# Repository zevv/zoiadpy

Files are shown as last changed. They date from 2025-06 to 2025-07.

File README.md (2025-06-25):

# Experimental external display for the Empress Zoia

The repo holds the source code and schematics/pcb design for an external
display for the Zoia. The Zoia comes with a screen so small you can cover it
with the tip of your pinky. This is barely usable when prgramming the Zoia on
your couch, but totally useless on stage when changing programs or parameters.

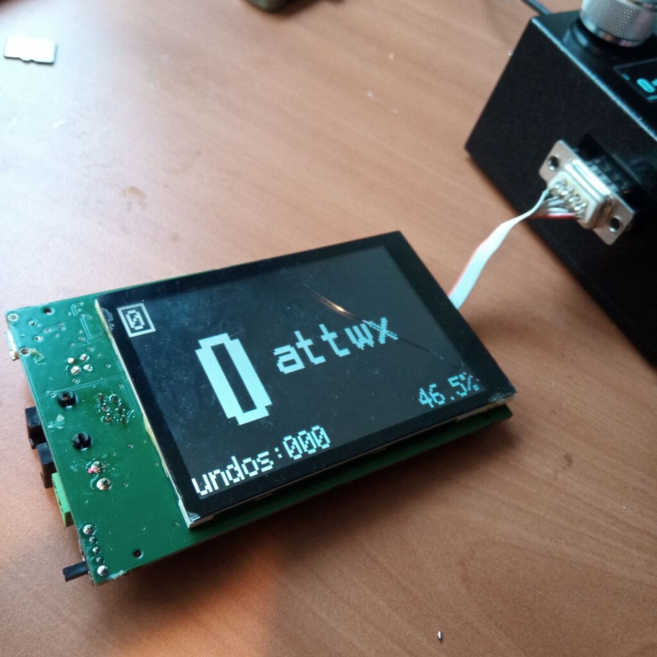
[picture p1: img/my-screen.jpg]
my-screen


This external display hooks onto the SPI bus between the Zoia en the tiny OLED
display and sniffs the screen contents when the display is updated. The screen
is upscaled to 480x320 resolution and sent to a second larger display.

The Zoia luckily exposes the OLED SPI on a friendly 2.54mm header row, so
anyone with basic soldering skills should be able to connect some wires to
these and feed them out of the box. I used a retro style DB9 type connector
for this myself, as this happened to be available in my parts drawer. You
need 5 wires in total, so any connector with enough pins should do:

- GND
- VCC
- MOSI
- CLK
- CS

# Disclaimer

I love this little project for me personally, but I do not recommend others to
go hack their Zoia: you will surely void the warranty of your box, and it is
very possible it will break in the process of adding the screen. Do not
complain to me when this happens.

# Software

Not too complicated: ESP32 has a bunch of SPI busses and supports both master
and slave mode. The OLED SPI is running in slave mode and handles all SPI
transfers of exactly 1024 bytes, as these contain the full updated screen data.
All other SPI transfers are simply ignored, as these contain the usual setup
parameters for the display.

The second SPI runs in master mode and drives an ILI4822 type TFT display which
I happened to have lying around. Although this is a full color display, it's
driven in 3 bits per pixel mode only to allow the big screen to keep up with
the OLED frame rate.

# Hardware

Kicad schematics and PCB design are available, but I have not yet produced this
as I'm happy to run on my current prototype hardware. I'm sure these are mostly
ok but someone will have to actually build and test these to make sure. I might
do this one day.

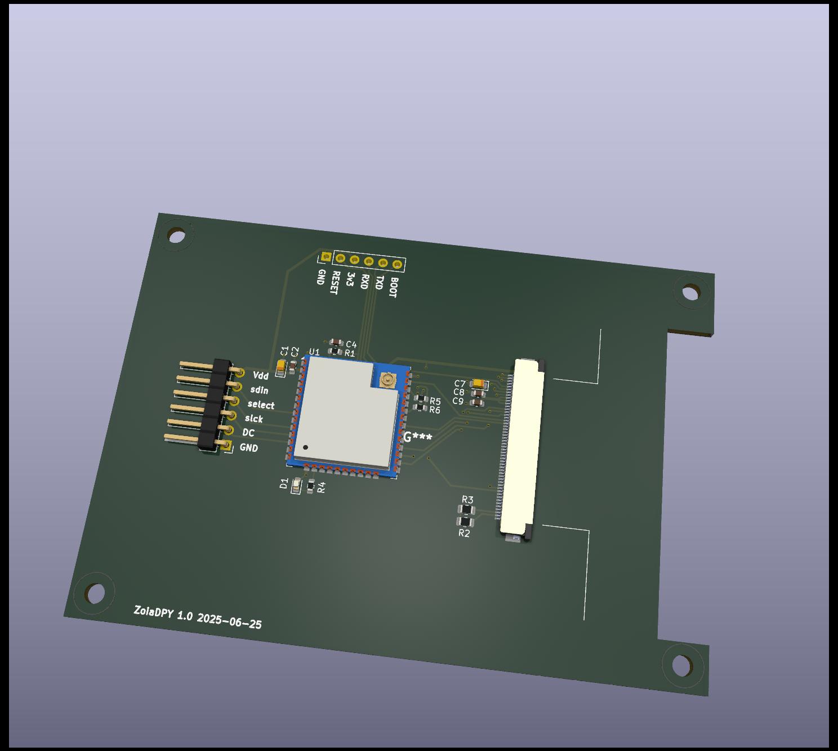
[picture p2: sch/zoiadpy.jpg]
pcb


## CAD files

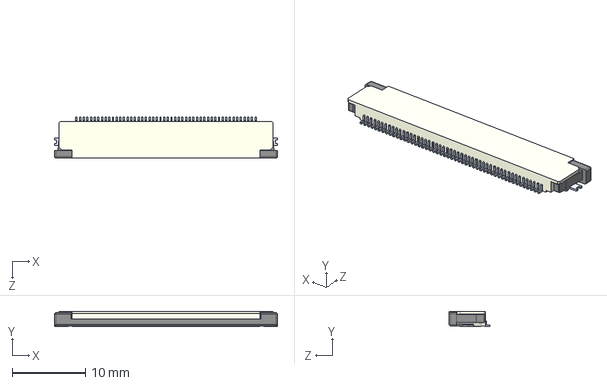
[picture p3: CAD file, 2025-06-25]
sch/62684-50210E9ALF.step
30.5 x 2.00 x 5.60 mm
62684 additional-21 body_50
pin^62684 additional-21 ASS x 50

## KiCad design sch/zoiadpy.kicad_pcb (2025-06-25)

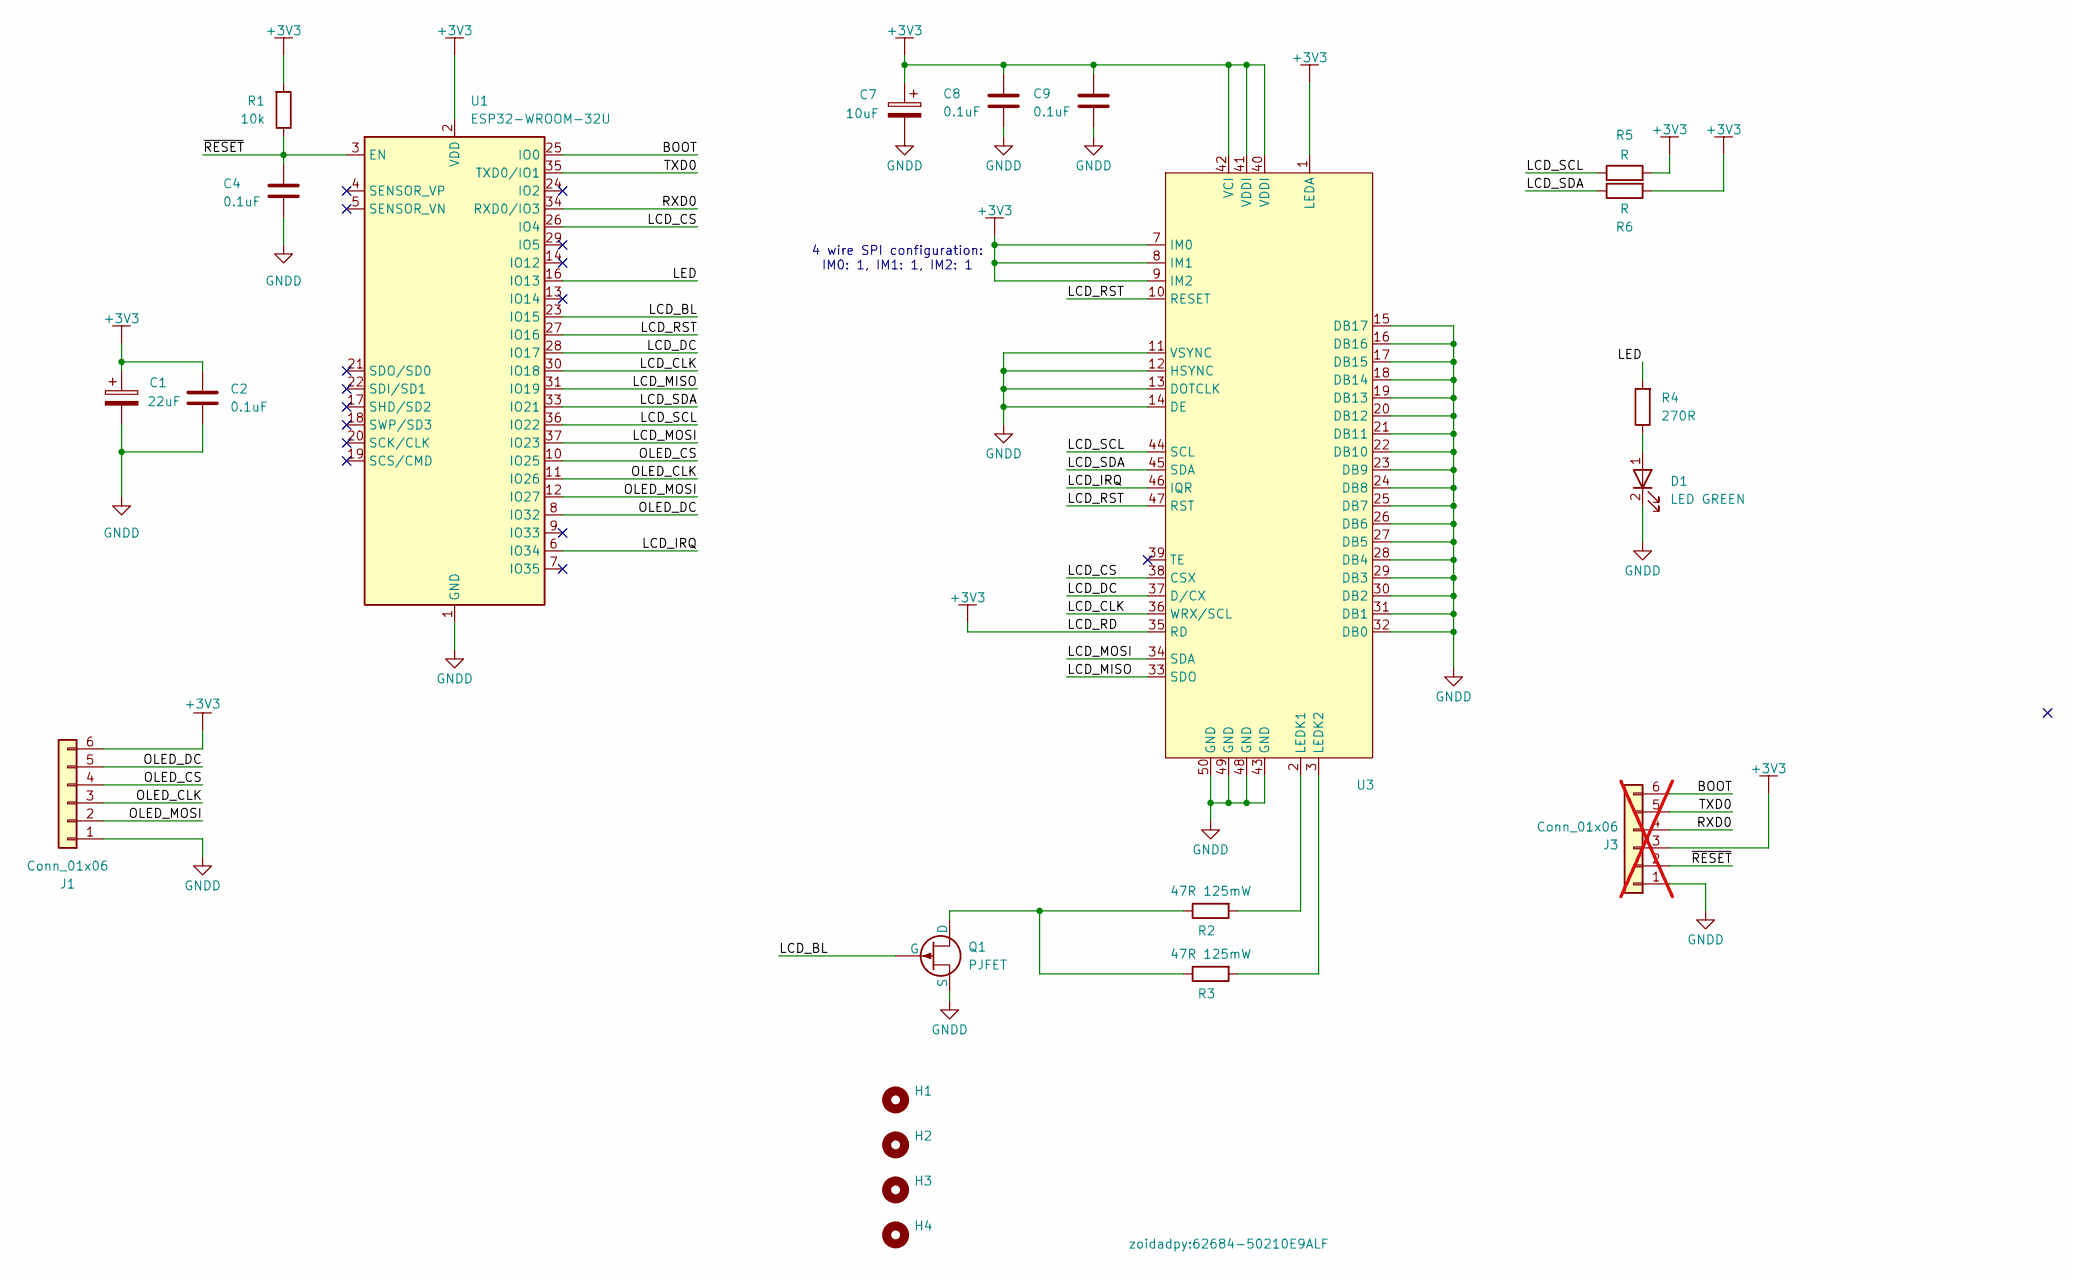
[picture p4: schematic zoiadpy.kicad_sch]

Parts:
C1: 22uF; CP_EIA-2012-12_Kemet-R; JLC C5674
C2, C4, C8, C9: 0.1uF; C_0603_1608Metric
C7: 10uF; CP_EIA-2012-12_Kemet-R; JLC C5674
D1: LED GREEN; LED_0603_1608Metric
H1, H2, H3, H4: MountingHole; MountingHole_3.2mm_M3
J1: Conn_01x06; PinHeader_1x06_P2.54mm_Horizontal
J3: Conn_01x06; PinHeader_1x06_P2.54mm_Vertical; not fitted
Q1: PJFET
R1: 10k; R_0603_1608Metric
R2, R3: 47R 125mW; R_0805_2012Metric
R4: 270R; R_0603_1608Metric; Farnell 2141320
R5, R6: R; R_0603_1608Metric
U1: ESP32-WROOM-32U
U3: 62684-50210E9ALF

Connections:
+3V3: C1.1, C2.1, C7.1, C8.1, C9.1, J1.6, J3.3, R1.2, R5.2, R6.2, U1.2 (VDD), U3.1 (LEDA), U3.7 (IM0), U3.8 (IM1), U3.9 (IM2), U3.35 (RD), U3.40 (VDDI), U3.41 (VDDI), U3.42 (VCI)
/BOOT: J3.6, U1.25 (IO0)
/LCD_BL: Q1.2 (G), U1.23 (IO15)
/LCD_CLK: U1.30 (IO18), U3.36 (WRX/SCL)
/LCD_CS: U1.26 (IO4), U3.38 (CSX)
/LCD_DC: U1.28 (IO17), U3.37 (D/CX)
/LCD_IRQ: U1.6 (IO34), U3.46 (IQR)
/LCD_MISO: U1.31 (IO19), U3.33 (SDO)
/LCD_MOSI: U1.37 (IO23), U3.34 (SDA)
/LCD_RST: U1.27 (IO16), U3.10 (RESET), U3.47 (RST)
/LCD_SCL: R5.1, U1.36 (IO22), U3.44 (SCL)
/LCD_SDA: R6.1, U1.33 (IO21), U3.45 (SDA)
/LED: R4.2, U1.16 (IO13)
/OLED_CLK: J1.3, U1.11 (IO26)
/OLED_CS: J1.4, U1.10 (IO25)
/OLED_DC: J1.5, U1.8 (IO32)
/OLED_MOSI: J1.2, U1.12 (IO27)
/RXD0: J3.4, U1.34 (RXD0/IO3)
/TXD0: J3.5, U1.35 (TXD0/IO1)
/~RESET: C4.1, J3.2, R1.1, U1.3 (EN)
GNDD: C1.2, C2.2, C4.2, C7.2, C8.2, C9.2, D1.2 (K), J1.1, J3.1, Q1.3 (S), U1.1 (GND), U1.15 (GND), U1.38 (GND), U1.39 (GND), U3.11 (VSYNC), U3.12 (HSYNC), U3.13 (DOTCLK), U3.14 (DE), U3.15 (DB17), U3.16 (DB16), U3.17 (DB15), U3.18 (DB14), U3.19 (DB13), U3.20 (DB12), U3.21 (DB11), U3.22 (DB10), U3.23 (DB9), U3.24 (DB8), U3.25 (DB7), U3.26 (DB6), U3.27 (DB5), U3.28 (DB4), U3.29 (DB3), U3.30 (DB2), U3.31 (DB1), U3.32 (DB0), U3.43 (GND), U3.48 (GND), U3.49 (GND), U3.50 (GND)
unnamed: D1.1 (A), R4.1
unnamed: Q1.1 (D), R2.1, R3.1
unnamed: R2.2, U3.2 (LEDK1)
unnamed: R3.2, U3.3 (LEDK2)

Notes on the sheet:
4 wire SPI configuration: IM0: 1, IM1: 1, IM2: 1

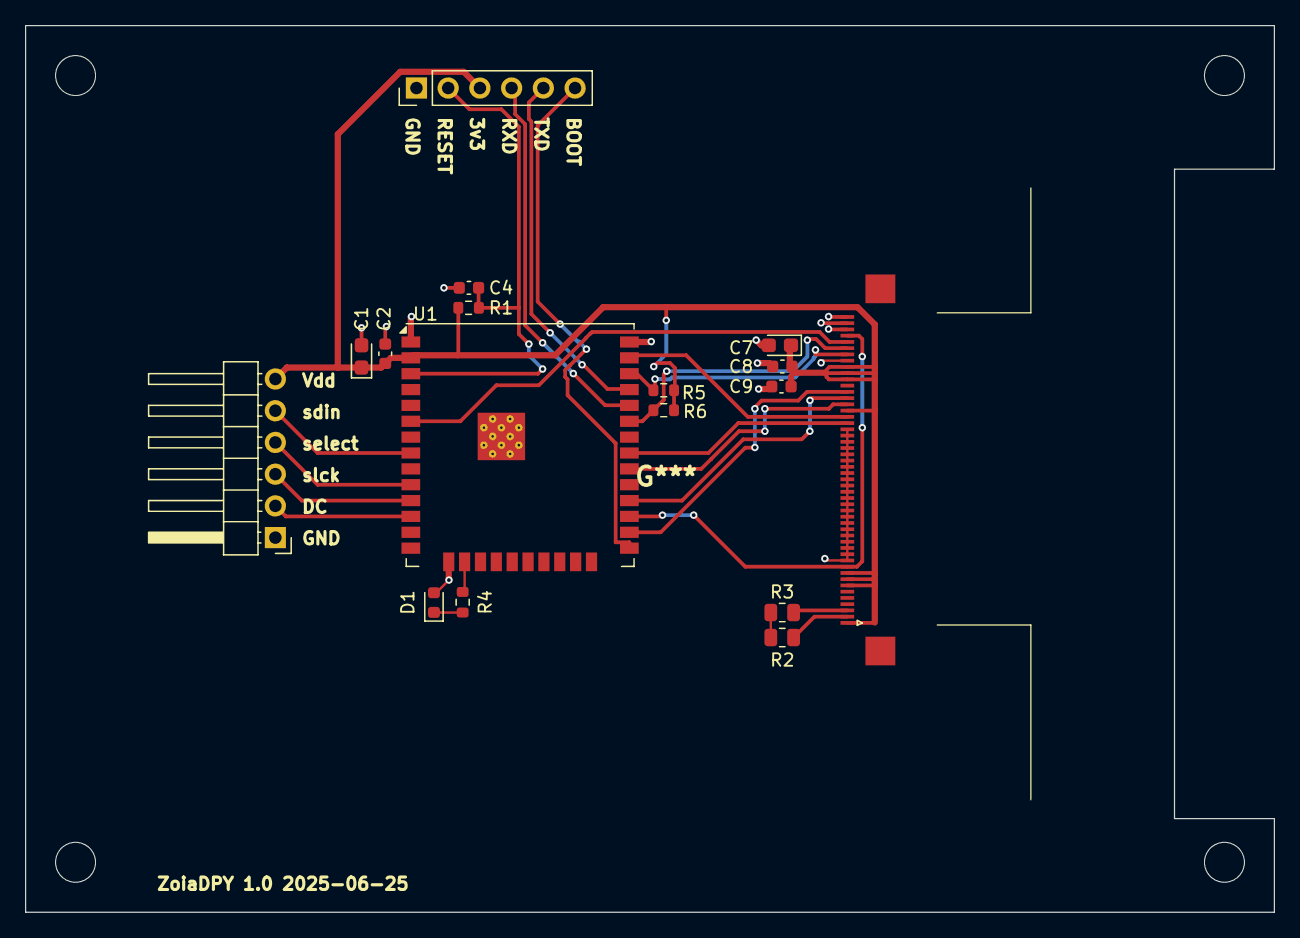
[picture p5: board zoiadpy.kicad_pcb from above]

Board: 2 copper layers, 100.0 x 71.0 mm, 21 parts (0 on the bottom side), 24 nets.

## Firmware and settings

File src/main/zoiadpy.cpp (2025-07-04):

#include <assert.h>
#include <stdio.h>
#include <stdint.h>
#include <string.h>
#include <stdlib.h>
#include <stdbool.h>
#include <stdarg.h>
#include <unistd.h>
#include <time.h>

#include "driver/spi_slave.h"  
#include "driver/gpio.h"     

#include "lcd.hpp"

// ideally buf_rx_count should be >1 to allow the SPI slave to have a nice
// pool of buffers, but i'm running into silly data corruption when running
// both SPI master and slaves at the same time. This might be related to
// https://github.com/espressif/esp-idf/issues/12354. For now keep to
// 1 rx_buffer: still not perfect but doable.

static const int buf_rx_count = 1;
static const int oled_w = 128;
static const int oled_h = 64;
static const int buf_rx_size = oled_w * oled_h / 8;


static void spi_init(void)
{
   spi_bus_config_t buscfg{};
   buscfg.mosi_io_num = 27;
   buscfg.miso_io_num = -1;
   buscfg.sclk_io_num = 26;
   buscfg.quadwp_io_num = -1;
   buscfg.quadhd_io_num = -1;
   buscfg.max_transfer_sz = 2048 * 8;

   spi_slave_interface_config_t slvcfg{};
   slvcfg.mode = 0;
   slvcfg.spics_io_num = 25;
   slvcfg.queue_size = buf_rx_count;
   slvcfg.flags = 0;

   int ret = spi_slave_initialize(SPI2_HOST, &buscfg, &slvcfg, SPI_DMA_CH_AUTO);
   assert(ret == ESP_OK);
}


static double hirestime(void)
{
   struct timespec ts;
   clock_gettime(CLOCK_MONOTONIC, &ts);
   return ts.tv_sec + ts.tv_nsec / 1e9;
}


static void copy_screen2(Lcd *lcd, uint8_t *buf_rx)
{
   static const int src_w = 128;
   static const int src_h = 64;
   static const int dst_w = 480;
   static const int dst_h = 320;
   static const int scale_y = dst_h / src_h;

   double t1 = hirestime();

   for(int y=0; y<src_h; y++) {

      // Decode one horizontal OLED line

      static uint8_t fb_src[src_w];
      for (int x=0; x<src_w; x++) {
         int o = (y / 8) * src_w + x;
         int b = y % 8;
         fb_src[x] = buf_rx[o] & (1 << b);
      }

      // Upscale to multiple LCD lines

      static uint8_t fb_dst[scale_y][dst_w / 2];
      int di = 0;
      int x = 0;
      while(x < dst_w) {
         uint8_t v = 0;
         if(fb_src[x++ * src_w / dst_w]) v |= (7 << 3);
         if(fb_src[x++ * src_w / dst_w]) v |= (7 << 0);
         for(int dy=0; dy<scale_y; dy++) {
            fb_dst[dy][di] = v;
         }
         di++;
      }

      Area area;
      area.x = 0;
      area.y = y * scale_y;
      area.w = dst_w;
      area.h = scale_y;
      lcd->disp_flush(&area, fb_dst[0]);
   }

   double t2 = hirestime();

   if(0) {
      printf("copy_screen2: %.3f\n", t2 - t1);
   }
}




static QueueHandle_t queue;


void task_lcd(void *arg)
{
   Lcd *lcd = new Lcd(GPIO_NUM_19, GPIO_NUM_23, GPIO_NUM_18);
   lcd->init();

   static uint8_t buf[buf_rx_size];

   for(;;) {
      xQueueReceive(queue, buf, portMAX_DELAY);
      copy_screen2(lcd, buf);
   }
}


void start(void)
{

   queue = xQueueCreate(buf_rx_count, buf_rx_size);
   xTaskCreate(task_lcd, "task_lcd", 8192, nullptr, 5, nullptr);

   // init spi and fill up the buffer pool
   spi_init();
   spi_slave_transaction_t ts[buf_rx_count]{};
   for(int i=0; i<buf_rx_count; i++) {
      spi_slave_transaction_t *t = &ts[i];
      t->length = buf_rx_size * 8;
      t->rx_buffer = spi_bus_dma_memory_alloc(SPI2_HOST, buf_rx_size, 0);
      t->user = (void *)i;
      int ret = spi_slave_queue_trans(SPI2_HOST, t, portMAX_DELAY);
      if(ret != ESP_OK) printf("spi_slave_queue_trans error %d\n", ret);
   }

   // main loop: pump the spi buffers and send off the received data. ideally
   // the spi_slave_transaction_t itself should be sent off and get requeued
   // from there, but that doesn't seem to be allowed from a different task
   int i =0;
   for(;;) {
      spi_slave_transaction_t *t;
      int ret = spi_slave_get_trans_result(SPI2_HOST, &t, portMAX_DELAY);
      if(ret == ESP_OK) {
         if(t->trans_len/8 == buf_rx_size) {
            if(0) ((uint8_t *)(t->rx_buffer))[i++ & 7] |= 0x01;
            xQueueSendToFront(queue, t->rx_buffer, portMAX_DELAY);
         } else {
            printf("xrun %d\n", t->trans_len/8);
            usleep(10 * 1000);
         }
         ret = spi_slave_queue_trans(SPI2_HOST, t, portMAX_DELAY);
         if(ret != ESP_OK) printf("spi_slave_queue_trans error %d\n", ret);
      }
   }
}

extern "C" {
void app_main()
{
   start();
}
}

// vi: ts=3 sw=3 et

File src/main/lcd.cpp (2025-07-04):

#include <stdio.h>
#include <string.h>
#include <driver/gpio.h>
#include "freertos/FreeRTOS.h"
#include "freertos/task.h"

#include "lcd.hpp"

gpio_num_t k_gpio_reset = GPIO_NUM_16;
gpio_num_t k_gpio_dc = GPIO_NUM_17;
gpio_num_t k_gpio_backlight = GPIO_NUM_15;

#define LCD_H_RES 480
#define LCD_V_RES 320
#define LCD_BUF_LINES 16



#define ILI9488_CMD_SLEEP_OUT                       0x11
#define ILI9488_CMD_POSITIVE_GAMMA_CORRECTION       0xE0
#define ILI9488_CMD_NEGATIVE_GAMMA_CORRECTION       0xE1
#define ILI9488_CMD_POWER_CONTROL_1                 0xC0
#define ILI9488_CMD_POWER_CONTROL_2                 0xC1
#define ILI9488_CMD_VCOM_CONTROL_1                  0xC5
#define ILI9488_CMD_MEMORY_ACCESS_CONTROL           0x36
#define ILI9488_CMD_COLMOD_PIXEL_FORMAT_SET         0x3A
#define ILI9488_CMD_INTERFACE_MODE_CONTROL          0xB0
#define ILI9488_CMD_FRAME_RATE_CONTROL_NORMAL       0xB1
#define ILI9488_CMD_DISPLAY_INVERSION_CONTROL       0xB4
#define ILI9488_CMD_DISPLAY_FUNCTION_CONTROL        0xB6
#define ILI9488_CMD_SET_IMAGE_FUNCTION              0xE9
#define ILI9488_CMD_WRITE_CTRL_DISPLAY              0x53
#define ILI9488_CMD_WRITE_DISPLAY_BRIGHTNESS        0x51
#define ILI9488_CMD_ADJUST_CONTROL_3                0xF7
#define ILI9488_CMD_DISPLAY_ON                      0x29
#define ILI9488_CMD_COLUMN_ADDRESS_SET              0x2A
#define ILI9488_CMD_PAGE_ADDRESS_SET                0x2B
#define ILI9488_CMD_MEMORY_WRITE                    0x2C
#define ILI9488_CMD_ALL_PIXELS_OFF                  0x22


// portrait: 0x48
// portrait_inverted: 0x88
// landscape: 0x28
// landscape_inverted: 0xE8

typedef struct {
    uint8_t cmd;
    uint8_t data[16];
    uint8_t databytes; //No of data in data; bit 7 = delay after set; 0xFF = end of cmds.
} lcd_init_cmd_t;


DRAM_ATTR static const lcd_init_cmd_t lcd_init_cmds[] = { 
   { ILI9488_CMD_SLEEP_OUT, { 0x00 }, 0x80 },
   { ILI9488_CMD_POSITIVE_GAMMA_CORRECTION, { 0x00, 0x03, 0x09, 0x08, 0x16, 0x0A, 0x3F, 0x78, 0x4C, 0x09, 0x0A, 0x08, 0x16, 0x1A, 0x0F }, 15 },
   { ILI9488_CMD_NEGATIVE_GAMMA_CORRECTION, { 0x00, 0x16, 0x19, 0x03, 0x0F, 0x05, 0x32, 0x45, 0x46, 0x04, 0x0E, 0x0D, 0x35, 0x37, 0x0F }, 15 },
   { ILI9488_CMD_POWER_CONTROL_1, { 0x17, 0x15 }, 2 },
   { ILI9488_CMD_POWER_CONTROL_2, { 0x41 }, 1 },
   { ILI9488_CMD_VCOM_CONTROL_1, { 0x00, 0x12, 0x80 }, 3 },
   { ILI9488_CMD_MEMORY_ACCESS_CONTROL, { 0x28 }, 1 },
   { ILI9488_CMD_COLMOD_PIXEL_FORMAT_SET, { 0x61 }, 1 },
   { ILI9488_CMD_INTERFACE_MODE_CONTROL, { 0x00 }, 1 },
   { ILI9488_CMD_FRAME_RATE_CONTROL_NORMAL, { 0xA0 }, 1 },
   { ILI9488_CMD_DISPLAY_INVERSION_CONTROL, { 0x02 }, 1 },
   { ILI9488_CMD_DISPLAY_FUNCTION_CONTROL, { 0x02, 0x02 }, 2 },
   { ILI9488_CMD_SET_IMAGE_FUNCTION, { 0x00 }, 1 },
   { ILI9488_CMD_WRITE_CTRL_DISPLAY, { 0x28 }, 1 },
   { ILI9488_CMD_WRITE_DISPLAY_BRIGHTNESS, { 0x7F }, 1 },
   { ILI9488_CMD_ADJUST_CONTROL_3, { 0xA9, 0x51, 0x2C, 0x02 }, 4 },
   { ILI9488_CMD_DISPLAY_ON, { 0x00 }, 0x80 },
   { 0, { 0 }, 0xff },
 };





void lcd_spi_pre_transfer_callback(spi_transaction_t *t)
{
    int dc = (int)t->user;
    gpio_set_level(k_gpio_dc, dc);
}


void lcd_cmd(spi_device_handle_t spi, const uint8_t cmd, bool keep_cs_active)
{
    spi_transaction_t t;
    memset(&t, 0, sizeof(t));
    t.length = 8;
    t.tx_buffer = &cmd;
    t.user = (void*)0;
    ESP_ERROR_CHECK(spi_device_polling_transmit(spi, &t));
}


void lcd_data(spi_device_handle_t spi, const uint8_t *data, int len)
{
   if(len > 0) {
      spi_transaction_t t;
      memset(&t, 0, sizeof(t));
      t.length = len*8;
      t.tx_buffer = data;
      t.user = (void*)1;
      ESP_ERROR_CHECK(spi_device_polling_transmit(spi, &t));
   }
}


void Lcd::disp_flush(const Area *area,  uint8_t *color_p)
{
   spi_transaction_t (&t)[6] = m_spi_transaction;
   memset(t, 0, sizeof(t));

   t[0].flags = SPI_TRANS_USE_TXDATA;
   t[0].length = 1 * 8;
   t[0].tx_data[0] = ILI9488_CMD_COLUMN_ADDRESS_SET;
   t[0].user = (void*)0;

   t[1].flags = SPI_TRANS_USE_TXDATA;
   t[1].length = 4 * 8;
   t[1].tx_data[0] = area->x >> 8;
   t[1].tx_data[1] = area->x >> 0;
   t[1].tx_data[2] = (area->x + area->w - 1) >> 8;
   t[1].tx_data[3] = (area->x + area->w - 1) >> 0;
   t[1].user = (void*)1;

   t[2].flags = SPI_TRANS_USE_TXDATA;
   t[2].length = 1 * 8;
   t[2].tx_data[0] = ILI9488_CMD_PAGE_ADDRESS_SET;
   t[2].user = (void*)0;

   t[3].flags = SPI_TRANS_USE_TXDATA;
   t[3].length = 4 * 8;
   t[3].tx_data[0] = area->y >> 8;
   t[3].tx_data[1] = area->y >> 0;
   t[3].tx_data[2] = (area->y + area->h - 1) >> 8;
   t[3].tx_data[3] = (area->y + area->h - 1) >> 0;
   t[3].user = (void*)1;

   t[4].flags = SPI_TRANS_USE_TXDATA;
   t[4].length = 1 * 8;
   t[4].tx_data[0] = ILI9488_CMD_MEMORY_WRITE;
   t[4].user = (void*)0;

   t[5].length = (area->w * area->h) * 4 - 32; // why?
   t[5].tx_buffer = color_p;
   t[5].user = (void*)1;

   for(int i=0; i<6; i++) {
      ESP_ERROR_CHECK(spi_device_polling_transmit(m_spidev, &t[i]));
   }

}


Lcd::Lcd(gpio_num_t gpio_miso, gpio_num_t gpio_mosi, gpio_num_t gpio_sclk)
   : m_npending(0)
   , m_gpio_miso(gpio_miso)
   , m_gpio_mosi(gpio_mosi)
        , m_gpio_sclk(gpio_sclk)
{
}


void Lcd::init()
{
   spi_bus_config_t buscfg;
   memset(&buscfg, 0, sizeof(buscfg));
   buscfg.miso_io_num = -1;
   buscfg.mosi_io_num = m_gpio_mosi;
   buscfg.sclk_io_num = m_gpio_sclk;
   buscfg.quadwp_io_num = -1;
   buscfg.quadhd_io_num = -1;
   buscfg.max_transfer_sz = 4096 * 8;
   ESP_ERROR_CHECK(spi_bus_initialize(SPI3_HOST, &buscfg, SPI_DMA_CH_AUTO));

   spi_device_interface_config_t devcfg;
   memset(&devcfg, 0, sizeof(devcfg));
   devcfg.clock_speed_hz = 40 * 1000 * 1000;
   devcfg.mode = 0;
   devcfg.spics_io_num = GPIO_NUM_4;
   devcfg.queue_size = 7;
   devcfg.pre_cb = lcd_spi_pre_transfer_callback;
   devcfg.flags = 0;

   ESP_ERROR_CHECK(spi_bus_add_device(SPI3_HOST, &devcfg, &m_spidev));

   gpio_config_t io_conf = {};
   io_conf.mode = GPIO_MODE_OUTPUT;
   io_conf.pin_bit_mask = (1ULL << k_gpio_reset)
                        | (1ULL << k_gpio_dc)
                        | (1ULL << k_gpio_backlight);
   gpio_config(&io_conf);
   gpio_set_level(k_gpio_backlight, 0);

   gpio_set_level(k_gpio_reset, 0);
   vTaskDelay(100 / portTICK_PERIOD_MS);
   gpio_set_level(k_gpio_reset, 1);
   vTaskDelay(100 / portTICK_PERIOD_MS);

   int cmd = 0;
   while (lcd_init_cmds[cmd].databytes != 0xff) {
      lcd_cmd(m_spidev, lcd_init_cmds[cmd].cmd, false);
      lcd_data(m_spidev, lcd_init_cmds[cmd].data, lcd_init_cmds[cmd].databytes & 0x1F);
      if (lcd_init_cmds[cmd].databytes & 0x80) {
         vTaskDelay(100 / portTICK_PERIOD_MS);
      }
      cmd++;
   }

   lcd_cmd(m_spidev, ILI9488_CMD_DISPLAY_ON, false);

   uint16_t black[480];
   memset(black, 0, sizeof(black));
   Area area;
   for(int y=0; y<320; y++) {
      area.x = 0;
      area.y = 0;
      area.w = 480;
      area.h = 1;
      disp_flush(&area, (uint8_t *)black);
   }

   gpio_set_level(k_gpio_backlight, 1);
}
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

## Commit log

2025-06-23 Initial checkin, decoding to uart works on ESP32
2025-06-23 updated SPI gpios
2025-06-25 Added schematics and pcB
    [62684-50210E9ALF.step, zoiadpy.kicad_pcb, zoiadpy.kicad_sch]
2025-06-28 changed spi buffer handling to avoid rx overruns
    [zoiadpy.cpp]
2025-07-04 more spi
2025-07-04 Once more refactored to get the DMA to behave
